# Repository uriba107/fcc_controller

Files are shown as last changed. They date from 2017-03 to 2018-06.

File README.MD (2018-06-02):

## FCC3 controller board
This Arduino Based project, is meant to allow FCC3 force sensing mod for Cougar, to be used with Thrustmaster Warthog without the need to use the old TM Cougar Electronics

This software is distributed under MIT license, and is provided as is and without any warranty what so ever. Further information can be found in "license.txt" which belongs to the LUFA framework on which controller code is based.

### Table Of Content
- [FCC3 controller board](#fcc3-controller-board)
  - [Features](#features)
  - [What settings are recommended](#what-settings-are-recommended)
  - [FLCS in F-16](#flcs-in-f-16)
      - [Analog FLCS](#analog-flcs)
      - [Digital FLCS](#digital-flcs)
  - [Cheat sheet](#cheat-sheet)
  - [BOM](#bom)

### Features
  * 11 bit output on Pitch and Roll.
  * Support for both Cougar and Warthog grips.
  * On the fly configuration changes:
    * Multiple force presets (9, 6 & 4.5 Kg/f), in addition to one user configurable sensitivity setting.
    * User toggleable, FLCS Based, realistic force ratios.  
    * User toggleable FLCS sensor rotation. In later blocks, the stick sensor is rotated clockwise to reduce accidental roll on pitch commands. Activating this option will simulate that.
    * on the fly re-centering (just in case).
  * Bi-Directional Control software:
    * Allows Joystick settings change (same as available via the grip).
    * Allows User configurable sensitivity setting to be set.
    * Handles Firmware upgrades for the stick.
    
**Note:** <br>
The code was developed with the help of ViperCore, makers of the FCC3. They have also produce a compatible board which can be purchsed either as a [Standalone board](http://www.vipercore.nl/index.php/webshop/view/productdetails/virtuemart_product_id/58/virtuemart_category_id/14) or [bundled with FCW1 module](http://www.vipercore.nl/index.php/webshop/view/productdetails/virtuemart_product_id/56/virtuemart_category_id/14)

### What settings are recommended
  FLCS and SSC config had changed over the years, so depending on what type of F-16 you want to model, settings will vary.

<b><u><i> Blocks 30/32 and before: </b></u></i>
  * Analog FLCS
  * Sensor Rotation -  Disabled

<b><u><i> Block 40/42 and after: </b></u></i>
  * Digital FLCS
  * Sensor Rotation - Enabled

### FLCS in F-16
There are two types of FLCS installed in F-16s.The controller attempts to emulate both system operational logic.</br>

In both cases, force ratio is maintained by the controller. The selected force setting is used as full pitch up command (which is the maximum required force), while pitch down and roll are proportional according to the FLCS version emulated.

#### Analog FLCS
  <b>Real life:</b><br>
   Full pitch up command is 180N (about 18Kgf), while full pitch down and full roll are 80N (or about 8Kgf).

  <b>Controller example:</b> in 9Kg/f mode, full pitch up will be 9kg/f for full deflection, but on the other axis, only 4kg/f will be required.

#### Digital FLCS
  <b>Real life:</b><br>
  full pitch up command is 25lbf, while full pitch down is 16lbf and full roll is 17lbf.

  <b>Controller example:</b><br>
  In 9kgf mode, Pitch up command will be  9kgf for full deflection. full pitch down will require 5.76kgf and full roll will require 6.12kgf.

### Cheat sheet
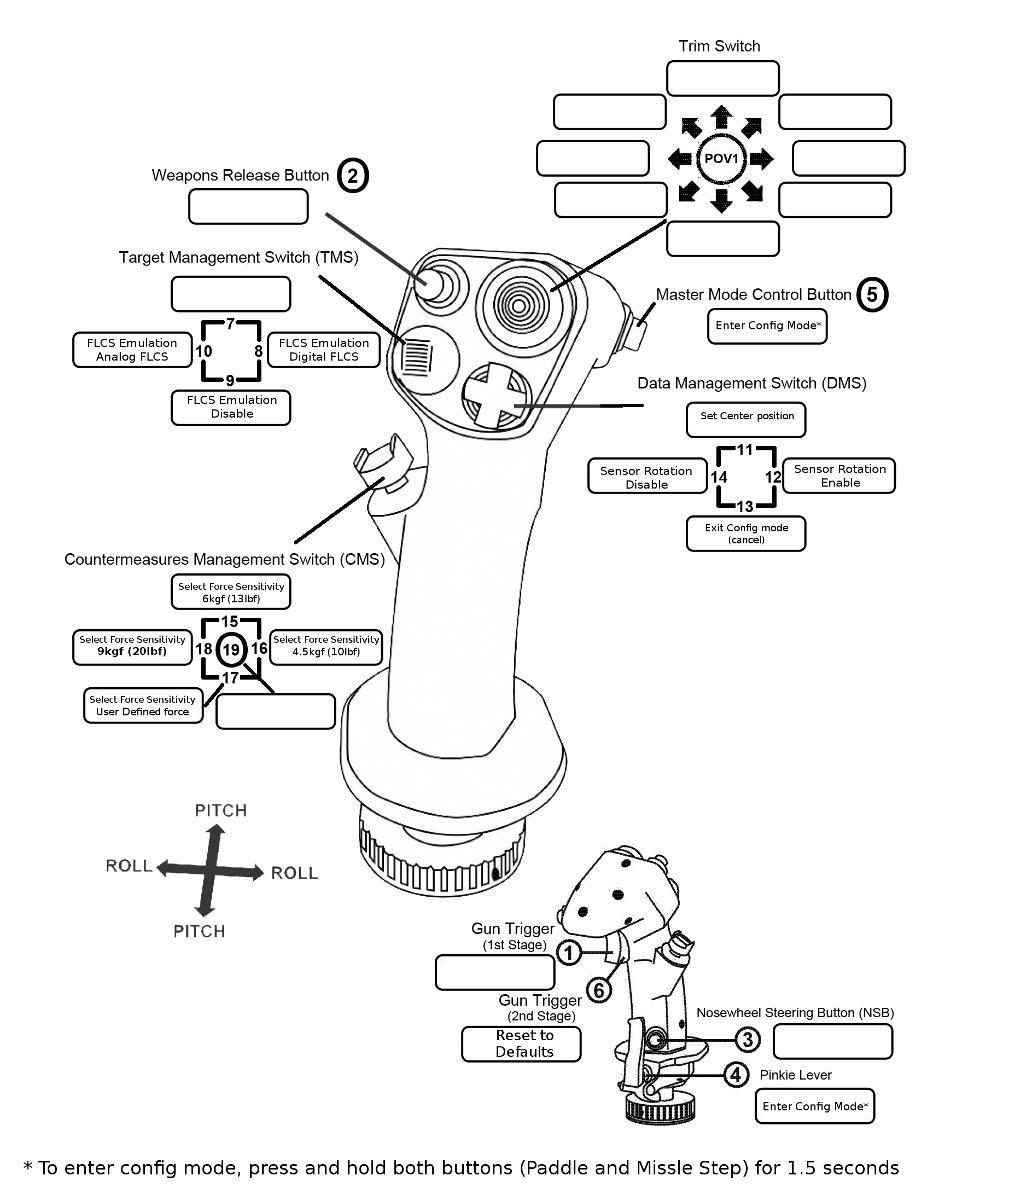
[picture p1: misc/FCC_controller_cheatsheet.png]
Image of fcc_controller button layout


### BOM
* Atmega 32U4 based board ([Arduino pro-micro](http://www.ebay.com/sch/i.html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) or an [Arduino Micro](https://www.arduino.cc/en/Main/arduinoBoardMicro) are recommended)
* [MCP3202](http://www.ebay.com/sch/i.html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) - 12 Bit external ADC
* A small protoboard (cheap dual sided 4*6 will be good enough)
* For Pro-micro - A momentary push button and 10+ Kohm resistor as the board has no reset switch.
* A few LEDs and resistors - for status.
* Header pins, two 3 pin headers and one 5 pins header, for grip and analog sensors. Generic 0.1" headers will do the trick. But correct header will be the [ JST EH series connectors](http://www.jst-belgium.be/productSeries.php?pid=46).
* Female Headers for the Arduino (optional)
* DIP8 socket for the MCP3202 (optional)

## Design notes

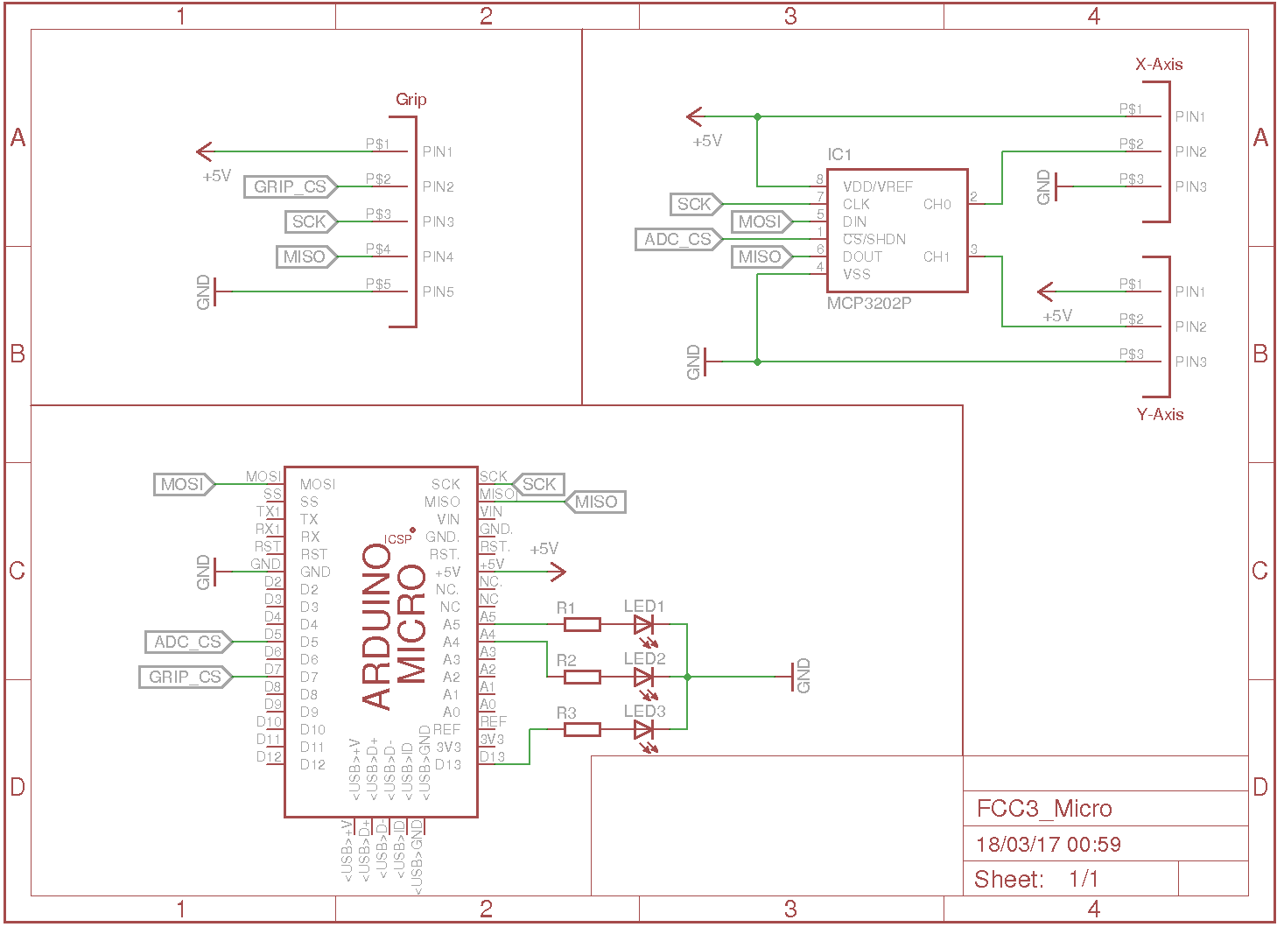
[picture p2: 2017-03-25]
Schematics/FCC3_Micro.png

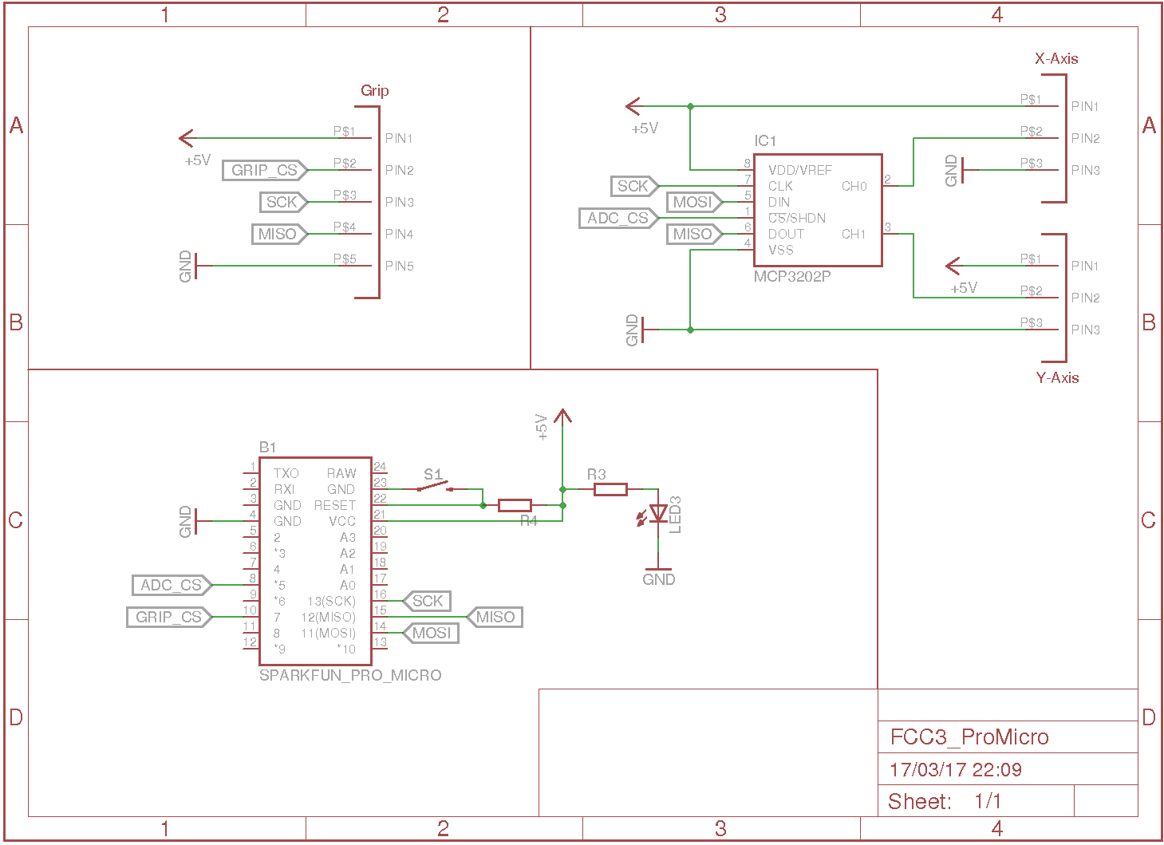
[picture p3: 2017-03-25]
Schematics/FCC3_ProMicro.png

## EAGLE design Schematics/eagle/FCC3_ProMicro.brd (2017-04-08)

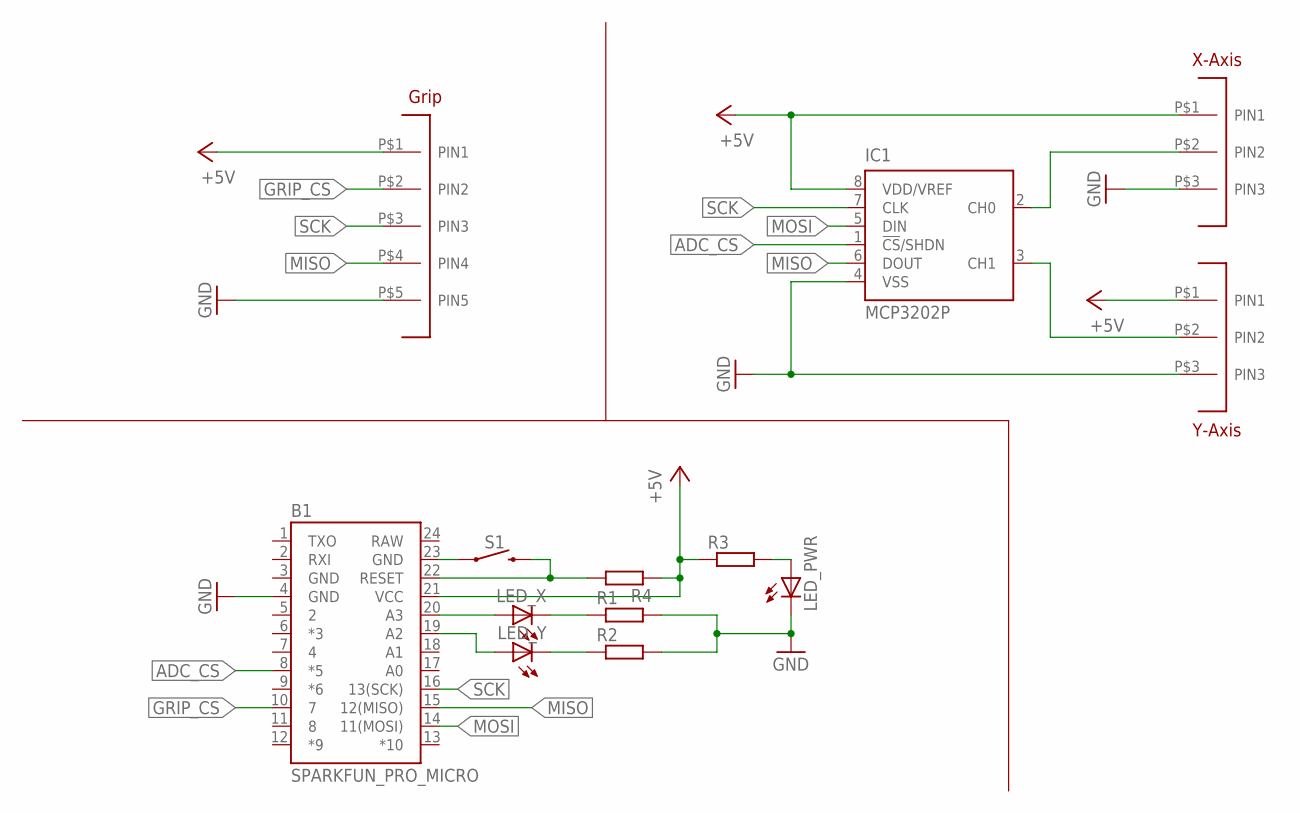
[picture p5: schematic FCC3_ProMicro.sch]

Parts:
B1: SPARKFUN_PRO_MICRO
IC1: MCP3202P; DIL8
LED_PWR: LED3MM
LED_X: LED3MM
LED_Y: LED3MM
R1, R2, R3, R4: R-EU_0204/5; 0204/5
S1: MOMENTARY-SWITCH-SPST-PTH-6.0MM; TACTILE_SWITCH_PTH_6.0MM
U$1, U$2: JST_EH_3PIN; JST-EH-3PIN
U$3: JST_EH_5PIN; JST-EH-5PIN

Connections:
+5V: B1.21 (VCC), IC1.8 (VDD/VREF), R3.1, R4.1, U$1.P$1 (PIN1), U$2.P$1 (PIN1), U$3.P$1 (PIN1)
ADC_CS: B1.8 (*5), IC1.1 (!CS!/SHDN)
GND: B1.3 (GND), B1.4 (GND), B1.23 (GND), IC1.4 (VSS), LED_PWR.K (C), R1.2, R2.2, S1.1, U$1.P$3 (PIN3), U$2.P$3 (PIN3), U$3.P$5 (PIN5)
GRIP_CS: B1.10 (7), U$3.P$2 (PIN2)
MISO: B1.15 (12(MISO)), IC1.6 (DOUT), U$3.P$4 (PIN4)
MOSI: B1.14 (11(MOSI)), IC1.5 (DIN)
unnamed: IC1.2 (CH0), U$2.P$2 (PIN2)
unnamed: IC1.3 (CH1), U$1.P$2 (PIN2)
unnamed: B1.20 (A3), LED_X.A
unnamed: B1.19 (A2), LED_Y.A
unnamed: LED_PWR.A, R3.2
unnamed: LED_Y.K (C), R2.1
unnamed: LED_X.K (C), R1.1
RAW: B1.24 (RAW)
RESET: B1.22 (RESET), R4.2, S1.3 (2)
SCK: B1.16 (13(SCK)), IC1.7 (CLK), U$3.P$3 (PIN3)

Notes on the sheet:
Grip
X-Axis
Y-Axis

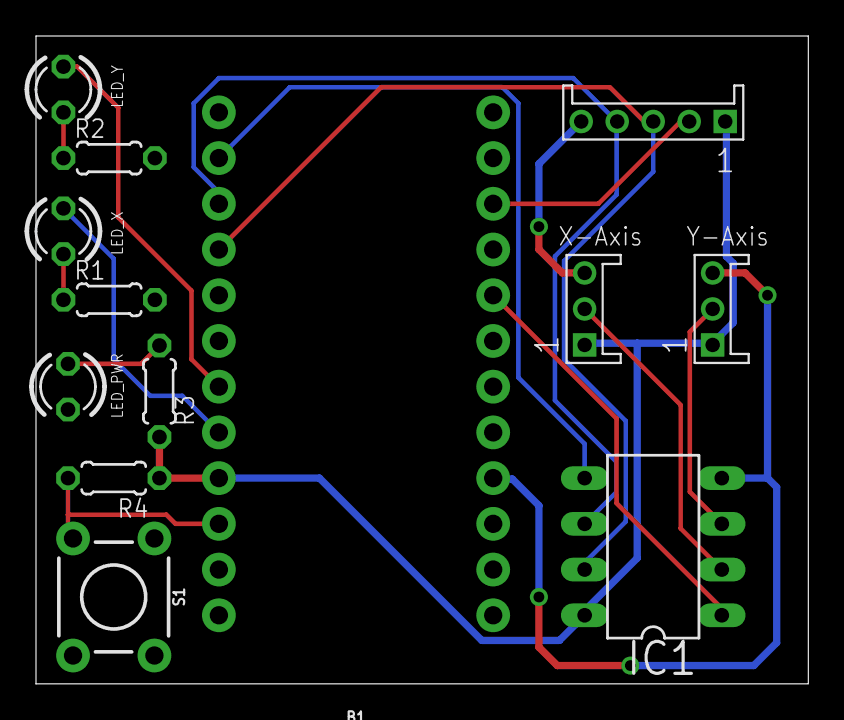
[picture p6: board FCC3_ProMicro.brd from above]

Board: 2 copper layers, 42.9 x 36.0 mm, 13 parts (0 on the bottom side), 15 nets.

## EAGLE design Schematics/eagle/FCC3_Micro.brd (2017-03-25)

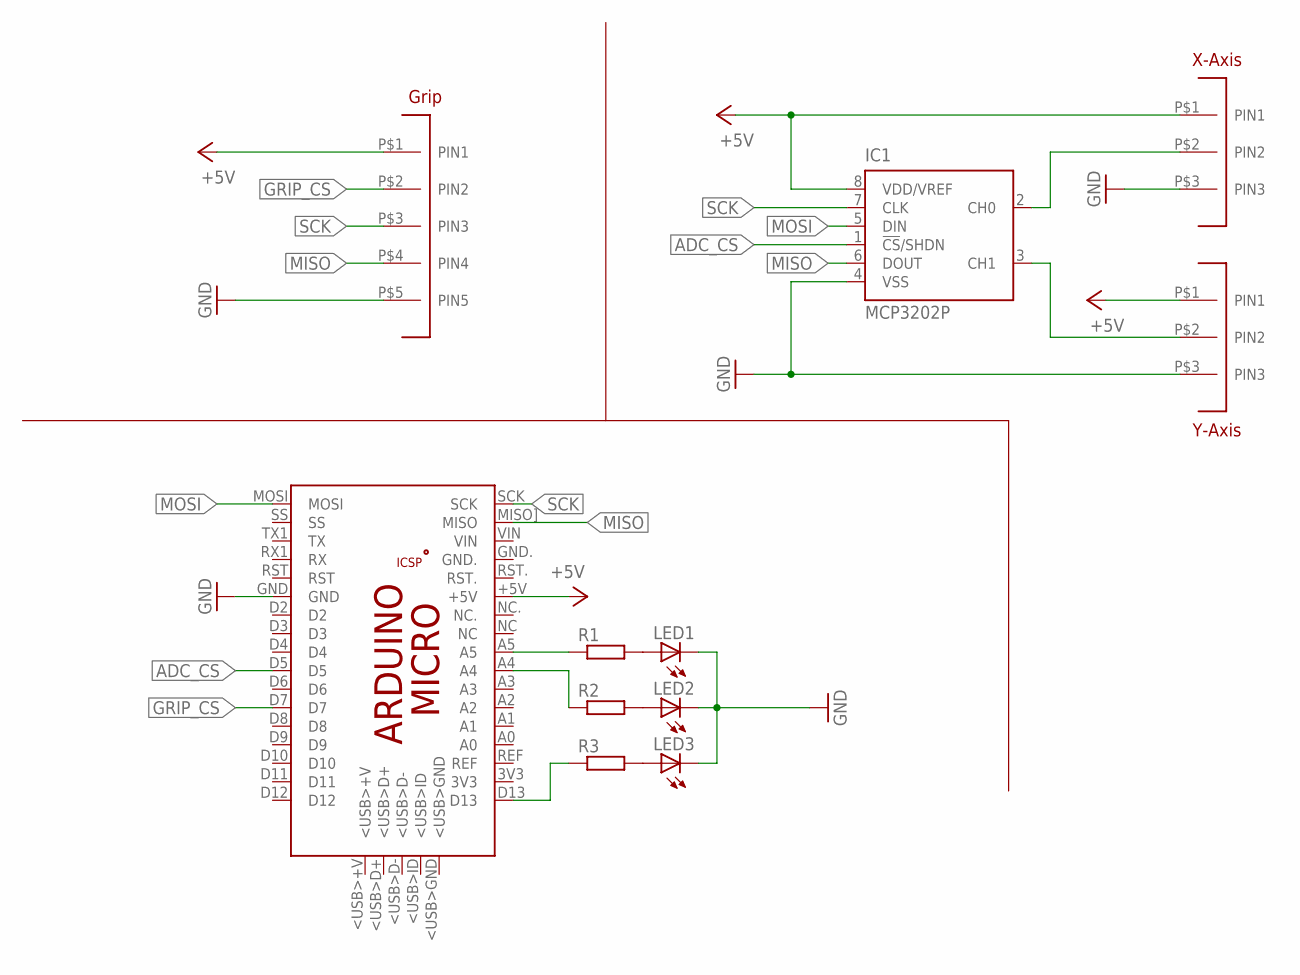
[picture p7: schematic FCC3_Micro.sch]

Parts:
IC1: MCP3202P; DIL8
LED1, LED2, LED3: LED5MM
PCB1: ARDUINO_MICRO
R1, R2, R3: R-EU_0204/5; 0204/5
U$1, U$2: JST_EH_3PIN; JST-EH-3PIN
U$3: JST_EH_5PIN; JST-EH-5PIN

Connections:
+5V: IC1.8 (VDD/VREF), PCB1.+5V, U$1.P$1 (PIN1), U$2.P$1 (PIN1), U$3.P$1 (PIN1)
ADC_CS: IC1.1 (!CS!/SHDN), PCB1.D5
GND: IC1.4 (VSS), LED1.K (C), LED2.K (C), LED3.K (C), PCB1.GND, U$1.P$3 (PIN3), U$2.P$3 (PIN3), U$3.P$5 (PIN5)
GRIP_CS: PCB1.D7, U$3.P$2 (PIN2)
MISO: IC1.6 (DOUT), PCB1.MISO] (MISO), U$3.P$4 (PIN4)
MOSI: IC1.5 (DIN), PCB1.MOSI
unnamed: IC1.2 (CH0), U$2.P$2 (PIN2)
unnamed: IC1.3 (CH1), U$1.P$2 (PIN2)
unnamed: LED3.A, R3.2
unnamed: LED1.A, R1.2
unnamed: LED2.A, R2.2
SCK: IC1.7 (CLK), PCB1.SCK, U$3.P$3 (PIN3)
STATUS: PCB1.D13, R3.1
X-LED: PCB1.A5, R1.1
Y-LED: PCB1.A4, R2.1

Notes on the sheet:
Grip
X-Axis
Y-Axis

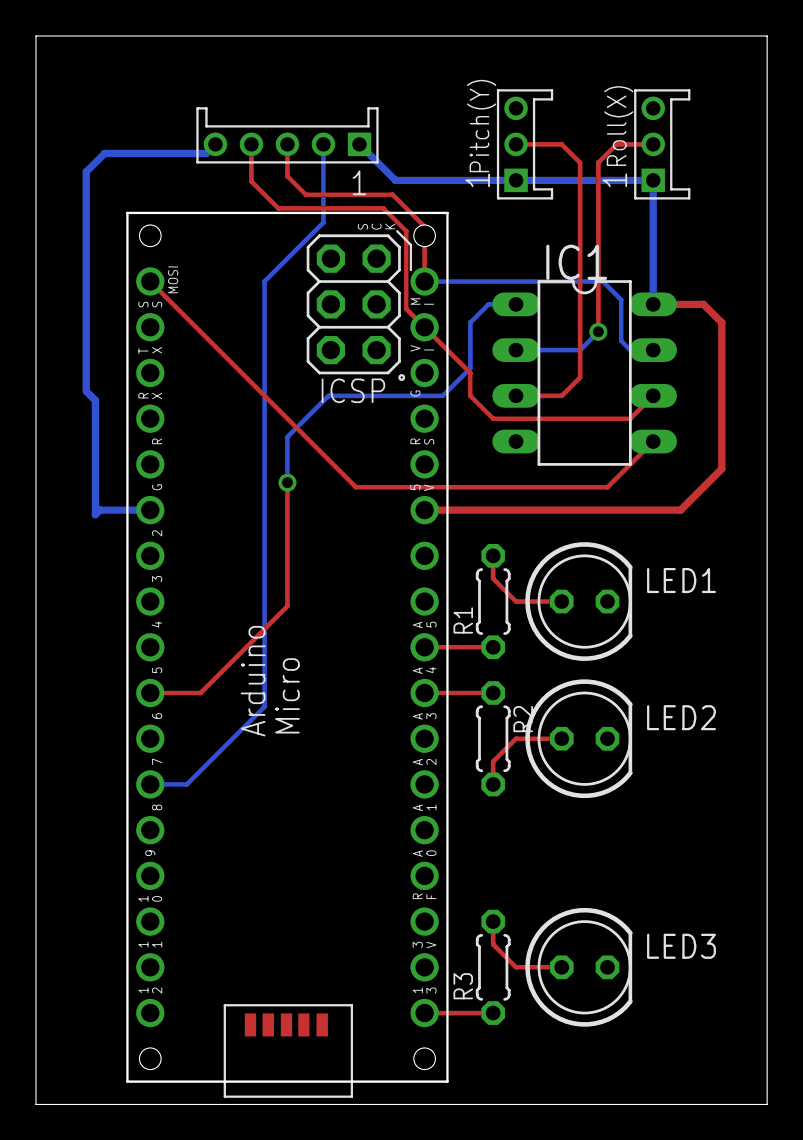
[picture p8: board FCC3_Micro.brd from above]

Board: 2 copper layers, 40.6 x 59.4 mm, 11 parts (0 on the bottom side), 15 nets.

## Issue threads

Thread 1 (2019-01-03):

USB FCC Controller

fusion79, 2019-01-03:
URI,
   Hi this is Fusion (aka viper44). Thanks for your contribution to making the fcc controller. I do have an issue with it and maybe you can help me and others. I have been having issues as far as the controller working on 3 separate computers in different ways. My laptop in a USB 3.0 port is working flawlessly with all current drivers installed for my usb hub on my laptop all buttons and axis work. The second pc which is my desk pc for everyday use as far as bills, letters, etc. works with most of the buttons till you get to the tms, dms, cms inputs and the nws buttons. They don't work or intermittent. All of the drivers are current. The axis' do work. This is plugging it into the usb 2.0 port on motherobard, usb 3.0 port on motherboard, and powered usb 2.0 hub plugged into a usb 2.0 port on motherboard. Last my simulator PC when I plug it into the usb 2.0 and 3.1 ports on my motherboard as well as powered usb 2.0 hub plugged into usb 2.0 on motherboard only the axis, 1st detent trigger, pickle buttons work and the hat only works in a few directions. Please help me with this issue as I really want to use your controller.
I have told quite a few people about your controllers, ded, pfld, ffl, etc. They are interested but hope the bugs will be fixed.
Thanks in advance.

Matt "Fusion"

uriba107, 2021-04-22:
closing

Closed 2021-04-22.

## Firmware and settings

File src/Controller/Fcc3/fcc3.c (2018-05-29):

#include "fcc3.h"

// configure Global EEPROM pointers
uint16_t EEMEM NonVolatileUserForce = FORCE_3KGF;
uint8_t EEMEM NonVolatileOptions = Force4Kg;
uint16_t EEMEM NonVolitileRotationCos = 978;
uint16_t EEMEM NonVolitileRotationSin = -207;

// Global vars to store EEPROM values for runtime
StickLimit gStickLimits;
uint8_t gOptions;
int16_t gUserDefinedForce;
int16_t gUserDefinedRotation[2];

// Global vars for Config modes
bool gIsConfig = false;
uint8_t gPowerLed = 255;
uint32_t gConfigTimer = 0;

/////////// Init/Setup Functions ////////////////
void InitFCC(void)
{
	SetupSPI();

	TimerInit();
	SetupLeds();
	// Now enable global interrupts
	sei();

	ReadStickZero();
	ReadMem();
}

void SetupSPI(void)
{
	// Set Grip CS (PE6 - Arduino Pin7)
	// CS should rest high
	DDRE |= (1 << DDE6);	// set to output
	PORTE |= (1 << PORTE6); // pull high

	// ADC CS (PC6 - Arduino Pin5)
	DDRC |= (1 << DDC6);
	PORTC |= (1 << PORTC6);

	SPI_Init(SPI_SPEED_FCPU_DIV_4 | SPI_MODE_MASTER);

	// Set PF0 and PF1 to output for Axis Zero Led
	// Done Here because ADC is check is driving those pins..
	// Also set PF4&5 for pro-micro
	DDRF |= (1 << PORTF0) | (1 << PORTF1) | (1 << PORTF4) | (1 << PORTF5);
}

void SetupLeds(void)
{
	// Set PC7 (Arduino Pin 13) For PWM
	// Set pin to output
	DDRC |= (1 << DDC7);

	// initiallize PWM4A
	// TCCR4A |= (1 << PWM4A)
	cbi(TCCR4A, COM4A0);

	// Now turn LED on for full cycle
	setStatusLed(gPowerLed);
}

void setStatusLed(uint8_t power)
{
	if (power == 0)
	{
		cbi(TCCR4A, COM4A1);
		PORTC &= ~(1 << PORTC7);
	}
	else if (power == 255)
	{
		cbi(TCCR4A, COM4A1);
		PORTC |= (1 << PORTC7);
	}
	else
	{
		// set timers. pin is OC4A in PMW
		//		TCCR4A |= (1 << PWM4A) |(1 << COM4A1);
		//		TCCR4A &= ~(1 << COM4A0);
		sbi(TCCR4A, COM4A1);
		OCR4A = power;
	}
}

///////// EEPROM /////////////////////
void WriteMem(void)
{
	// This function will write to EEPROM any values that had been changed in runtime (to save EEPROM lifetime)
	uint8_t volatile VolatileOptions;

	int16_t volatile VolatileUserForce;

	int16_t volatile VolitileRotationCos;
	int16_t volatile VolitileRotationSin;

	// Read EEPROM
	VolatileOptions = eeprom_read_byte(&NonVolatileOptions);
	VolatileUserForce = eeprom_read_word(&NonVolatileUserForce);

	VolitileRotationCos = eeprom_read_word(&NonVolitileRotationCos);
	VolitileRotationSin = eeprom_read_word(&NonVolitileRotationSin);

	VolatileUserForce &= ~(0xF000); //Really make sure reboot and center flags don't carry over
	gUserDefinedForce &= ~(0xF000);

	// Compare values and write back
	if (VolatileOptions != gOptions)
	{
		//gOptions &= ~(RebootDevice); //make sure RebootFlag doesn't carry over
		eeprom_update_byte(&NonVolatileOptions, gOptions);
	}

	if (gUserDefinedForce != VolatileUserForce)
	{
		eeprom_update_word(&NonVolatileUserForce, gUserDefinedForce);
	}

	eeprom_update_word(&NonVolitileRotationCos, VolitileRotationCos);
	eeprom_update_word(&NonVolitileRotationSin, VolitileRotationSin);
}

void ReadMem(void)
{
	uint8_t volatile VolatileOptions;
	int16_t volatile VolatileUserForce;

	int16_t volatile VolitileRotationCos;
	int16_t volatile VolitileRotationSin;

	// Read EEPROM
	VolatileOptions = eeprom_read_byte(&NonVolatileOptions);
	//VolatileOptions &= ~(RebootDevice); //make sure RebootFlag doesn't carry over
	VolatileUserForce = eeprom_read_word(&NonVolatileUserForce);
	VolatileUserForce &= ~(0xF000); //Really make sure reboot and center flags don't carry over

	VolitileRotationCos = eeprom_read_word(&NonVolitileRotationCos);
	VolitileRotationSin = eeprom_read_word(&NonVolitileRotationSin);

// Check and place values
	// result = a > b ? x : y;

	gOptions = EEPROM_EMPTY_BYTE(VolatileOptions) ? Force4Kg : VolatileOptions;
	gUserDefinedForce = EEPROM_EMPTY_WORD(VolatileUserForce) ? FORCE_3KGF : VolatileUserForce;

	gUserDefinedRotation[0] = EEPROM_EMPTY_WORD(VolitileRotationCos) ? ROT_COS : VolitileRotationCos;
	gUserDefinedRotation[1] = EEPROM_EMPTY_WORD(VolitileRotationSin) ? ROT_SIN : VolitileRotationSin;

	// do all the force calcs on init.
	ChangeSensitivity(gOptions);
}

////////////////////// Stick Config functions ////////////////////////////

void ReadStickZero(void)
{
	gStickLimits.X.center = (int32_t)(ReadRoll + ReadRoll + ReadRoll + ReadRoll + ReadRoll) / 5;
	gStickLimits.Y.center = (int32_t)(ReadPitch + ReadPitch + ReadPitch + ReadPitch + ReadPitch) / 5;
}

void ChangeSensitivity(uint8_t sensitivity)
{
	// Clear current force settings
	gOptions &= ~(ForceAll);
	// now set sensitivity bit
	gOptions |= (sensitivity);

	// now load correct config
	if (gOptions & Force4Kg)
	{
		SetCalibratedSensitivity(CalcForceDisplacement(4.5));
	}
	else if (gOptions & Force6Kg)
	{
		SetCalibratedSensitivity(CalcForceDisplacement(6.0));
	}
	else if (gOptions & Force9Kg)
	{
		SetCalibratedSensitivity(CalcForceDisplacement(9.0));
	}
	else
	{
		SetCalibratedSensitivity(gUserDefinedForce);
	}
}

void SetCalibratedSensitivity(int16_t OffsetValue)
{
	OffsetValue &= ~(0xF000);
	gStickLimits.X.max = OffsetValue;
	gStickLimits.X.min = -OffsetValue;
	gStickLimits.Y.max = OffsetValue;
	gStickLimits.Y.min = -OffsetValue;
	gStickLimits.Deadzone = 10 + (2 * (float)STICK_DEADZONE * ((float)OffsetValue / 2048));

	// do all the force calcs.
	CalcForceMapping();
}

void CalcForceMapping(void)
{
	// do all the force calcs.
	gStickLimits.FlcsUp = abs(gStickLimits.Y.max);
	if (gOptions & DigitalFlcs)
	{
		gStickLimits.FlcsDn = abs(gStickLimits.FlcsUp / 1.5625);
		gStickLimits.FlcsRoll = abs(gStickLimits.FlcsUp / 1.4705);
	}
	else
	{
		gStickLimits.FlcsDn = abs(gStickLimits.FlcsUp / 2.25);
		gStickLimits.FlcsRoll = abs(gStickLimits.FlcsUp / 2.25);
	}
}

int16_t CalcForceDisplacement(float RequestedForce)
{
	// Hardware: 9kg/f = 2Volt Delta
	// ADC: 5V = 4096
	// Middle Voltage: 2.5V

	float DeltaVol = 1.5;
	if (gOptions & FccWhGains)
	{
		DeltaVol = 2.0;
	}
// const float DeltaVol = 2.0F;
// const float ForceRef = 9.0F;
#define FORCE_REF 9
#define ADC_MAX 4095
#define VREF 5.0
#define BASEVOLTAGE 2.5

	float voltage = ((DeltaVol / FORCE_REF) * RequestedForce) + BASEVOLTAGE;

	float Retval = ((ADC_MAX / VREF) * voltage) - (ADC_MAX / 2);

	return (int16_t)Retval;
}
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

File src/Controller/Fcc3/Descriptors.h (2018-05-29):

/*
             LUFA Library
     Copyright (C) Dean Camera, 2015.

  dean [at] fourwalledcubicle [dot] com
           www.lufa-lib.org
*/

/*
  Copyright 2015  Dean Camera (dean [at] fourwalledcubicle [dot] com)

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
  The author disclaims all warranties with regard to this
  software, including all implied warranties of merchantability
  and fitness.  In no event shall the author be liable for any
  special, indirect or consequential damages or any damages
  whatsoever resulting from loss of use, data or profits, whether
  in an action of contract, negligence or other tortious action,
  arising out of or in connection with the use or performance of
  this software.
*/

/** \file
 *
 *  Header file for Descriptors.c.
 */

#ifndef _DESCRIPTORS_H_
#define _DESCRIPTORS_H_

	/* Includes: */
		#include <LUFA/Drivers/USB/USB.h>

		#include <avr/pgmspace.h>

	/* Type Defines: */
		/** Type define for the device configuration descriptor structure. This must be defined in the
		 *  application code, as the configuration descriptor contains several sub-descriptors which
		 *  vary between devices, and which describe the device's usage to the host.
		 */
		typedef struct
		{
			USB_Descriptor_Configuration_Header_t Config;

			// Joystick HID Interface
			USB_Descriptor_Interface_t            HID_Interface;
			USB_HID_Descriptor_HID_t              HID_JoystickHID;
			USB_Descriptor_Endpoint_t             HID_ReportINEndpoint;
			USB_Descriptor_Endpoint_t             HID_ReportOUTEndpoint;
		} USB_Descriptor_Configuration_t;

		/** Enum for the device interface descriptor IDs within the device. Each interface descriptor
		 *  should have a unique ID index associated with it, which can be used to refer to the
		 *  interface from other descriptors.
		 */
		enum InterfaceDescriptors_t
		{
			INTERFACE_ID_Joystick = 0, /**< Joystick interface descriptor ID */
		};

		/** Enum for the device string descriptor IDs within the device. Each string descriptor should
		 *  have a unique ID index associated with it, which can be used to refer to the string from
		 *  other descriptors.
		 */
		enum StringDescriptors_t
		{
			STRING_ID_Language     = 0, /**< Supported Languages string descriptor ID (must be zero) */
			STRING_ID_Manufacturer = 1, /**< Manufacturer string ID */
			STRING_ID_Product      = 2, /**< Product string ID */
		};

	/* Macros: */
		/** Endpoint address of the Joystick HID reporting IN endpoint. */
		#define JOYSTICK_EPADDR           (ENDPOINT_DIR_IN | 1)

		/** Endpoint address of the Joystick HID reporting OUT endpoint. */
		#define JOYSTICK_OUT_EPADDR       (ENDPOINT_DIR_OUT | 2)

		/** Size in bytes of the Joystick HID reporting IN endpoint. */
		#define JOYSTICK_EPSIZE           12

		/** Size in bytes of the Joystick HID reporting OUT endpoint. */
		#define JOYSTICK_OUT_EPSIZE       3

		/** Descriptor header type value, to indicate a HID class HID descriptor. */
		#define DTYPE_HID                 0x21

		/** Descriptor header type value, to indicate a HID class HID report descriptor. */
		#define DTYPE_Report              0x22

	/* Function Prototypes: */
		uint16_t CALLBACK_USB_GetDescriptor(const uint16_t wValue,
		                                    const uint16_t wIndex,
		                                    const void** const DescriptorAddress)
		                                    ATTR_WARN_UNUSED_RESULT ATTR_NON_NULL_PTR_ARG(3);

#endif

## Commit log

2017-03-16 change poll reate to 4ms, reprisenting 250Hz
2017-03-25 Added Micro/Pro-Micro schematics and boards
    [FCC3_Micro.brd, FCC3_Micro.sch, FCC3_ProMicro.brd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]
2017-03-25 New PID
    Cleanup some old functions as well.
2017-04-01 Firmware 0.1.3 New PID and some better comms with PC software
2017-04-08 replace force mapping with Analog/Digital FLCS
    [FCC3_ProMicro.brd, FCC3_ProMicro.sch]
2017-04-10 replace "center" button with "read settings"
2017-04-11 moved buttons around
2017-12-18 button layout image
2018-01-05 Potential fix for EEPROM loading issue
    [fcc3.c]

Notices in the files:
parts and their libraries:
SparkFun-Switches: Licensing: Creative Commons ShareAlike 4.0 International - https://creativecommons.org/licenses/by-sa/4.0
